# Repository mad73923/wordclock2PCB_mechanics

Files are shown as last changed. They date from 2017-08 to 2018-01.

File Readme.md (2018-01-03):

## Todos
- NRST C?
- ESP GPIO2 Pullup?
- SD CS
- Crystals C?
- SD Card shield
⁻ no THT components due to wall mount!?
- PCB boarder <-> Trace 0.25mm
- C instead of Bat?
- User Button debounce like F746 Discovery
- USB next to SD

### Copper: 2oz!

- Check USART Bootloader Pin capability!!! http://www.st.com/content/ccc/resource/technical/document/application_note/b9/9b/16/3a/12/1e/40/0c/CD00167594.pdf/files/CD00167594.pdf/jcr:content/translations/en.CD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

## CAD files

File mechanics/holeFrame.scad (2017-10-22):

// size - [x,y,z]
// radius - radius of corners
module roundedRect(size, radius)
{
	x = size[0];
	y = size[1];
	z = size[2];

	linear_extrude(height=z)
	hull()
	{
		// place 4 circles in the corners, with the given radius
		translate([(-x/2)+(radius/2), (-y/2)+(radius/2), 0])
		circle(r=radius);
	
		translate([(x/2)-(radius/2), (-y/2)+(radius/2), 0])
		circle(r=radius);
	
		translate([(-x/2)+(radius/2), (y/2)-(radius/2), 0])
		circle(r=radius);
	
		translate([(x/2)-(radius/2), (y/2)-(radius/2), 0])
		circle(r=radius);
	}
}

pcbMountR = 1;

module holeFrame(){
	difference(){
		cube([388,388,10]);
		translate([14+10+20/6,14+10+20/6,0]){
			for(i=[0:10]){
				for(j=[0:9]){
					translate([i*100/3,j*100/3,0])
						cylinder(30,14,14,true);
				}
			}
		}
        // minutes holes
        translate([388/2-(3*100/3)/2,11*100/3-15,0]){
            for(i=[0:3]){
                translate([i*100/3,0,0])
                cylinder(30,5,5,true);
            }
        }
        // ambient light sensor
        translate([388/2,11*100/3,0]){
            cylinder(30,5,5,true);
        }
        // PCB cutout
        translate([388/2-100/3,11*100/3+8.8,-1]){
            roundedRect([45,30,15],5);
        }
        translate([388/2+100/3,11*100/3+8.8,-1]){
            roundedRect([45,30,15],5);
        }
        //nose
        translate([388/2-10,11*100/3+8,-1]){
            cube([40,40,15]);
        }
        //cable input
        translate([388/2-55,11*100/3+6.5,-1])
            roundedRect([30,10,15],5);
        translate([388/2+55,11*100/3+6.5,-1])
            roundedRect([30,10,15],5);
        // PCB holes
        translate(pcbroot){
            translate([pcbHoleGap,pcbHoleGap,1])
            cylinder(30,pcbMountR,pcbMountR,true);
            translate([4,pcbsize[1]-pcbHoleGap,1])
            cylinder(30,pcbMountR,pcbMountR,true);
            translate([pcbsize[0],0,0]){
                translate([-pcbHoleGap,pcbHoleGap,1])
                cylinder(30,pcbMountR,pcbMountR,true);
                translate([-pcbHoleGap,pcbsize[1]-pcbHoleGap,1])
                cylinder(30,pcbMountR,pcbMountR,true);
            }
        }
	}
}

maskGerman = "ESXISTKFÜNFZEHNZWANZIGVIERTELGVORNACHBJSHALBEINSMJWZWEIDREIKFFVIERFÜNFJWSECHSSIEBENLACHTNEUNZEHNELFZWÖLFPCMUHR";
maskSwissGerman =  "ESKISCHAFÜFVIERTUBFZÄÄZWÄNZGSIVORABOHAUBIEPMEISZWÖISDRÜVIERIFÜFIQTSÄCHSISIBNIACHTINÜNIELZÄNIERBEUFIZWÖUFIAMUHR";

maskText = maskGerman;
maskFont = "Stencilia\\-A:style=Regular";
//maskFont = "Ruler Stencil Heavy:style=Standard";

module mask(){
	difference(){
		color("silver")
		cube([388,388,2]);
        translate([14+10+20/6,14+10+20/6,-1]){
			for(i=[0:9]){
				for(j=[0:10]){
					translate([j*100/3,i*100/3,0])
                    rotate([0,0,180])
						linear_extrude(height=5) text(maskText[i*11+10-j],  size=17.5, halign="center", valign="center", font=maskFont);
				}
			}
		}
        // minutes holes
        translate([388/2-(3*100/3)/2,11*100/3-15,0]){
            for(i=[0:3]){
                translate([i*100/3,0,0])
                cylinder(30,3,3,true);
            }
        }
        // ambient light sensor
        translate([388/2,11*100/3,0]){
            cylinder(30,3,3,true);
        }
	}
}

pcbroot = [388/2-65,11*100/3-9+1/3,-2];
pcbsize = [130,30,2];
pcbHoleR= 1.6;
pcbHoleGap = 4;

module pcb(){
    difference(){
        color("green")
        cube(pcbsize);
        translate([pcbHoleGap,pcbHoleGap,1])
        cylinder(5,pcbHoleR,pcbHoleR,true);
        translate([4,pcbsize[1]-pcbHoleGap,1])
        cylinder(5,pcbHoleR,pcbHoleR,true);
        translate([pcbsize[0],0,0]){
            translate([-pcbHoleGap,pcbHoleGap,1])
            cylinder(5,pcbHoleR,pcbHoleR,true);
            translate([-pcbHoleGap,pcbsize[1]-pcbHoleGap,1])
            cylinder(5,pcbHoleR,pcbHoleR,true);
        }
        translate([pcbsize[0]/2,8+2/3,0])
        cylinder(5,5,5,true);
    }
}

holeFrame();
translate([0,0,10]) mask();
translate(pcbroot) pcb();

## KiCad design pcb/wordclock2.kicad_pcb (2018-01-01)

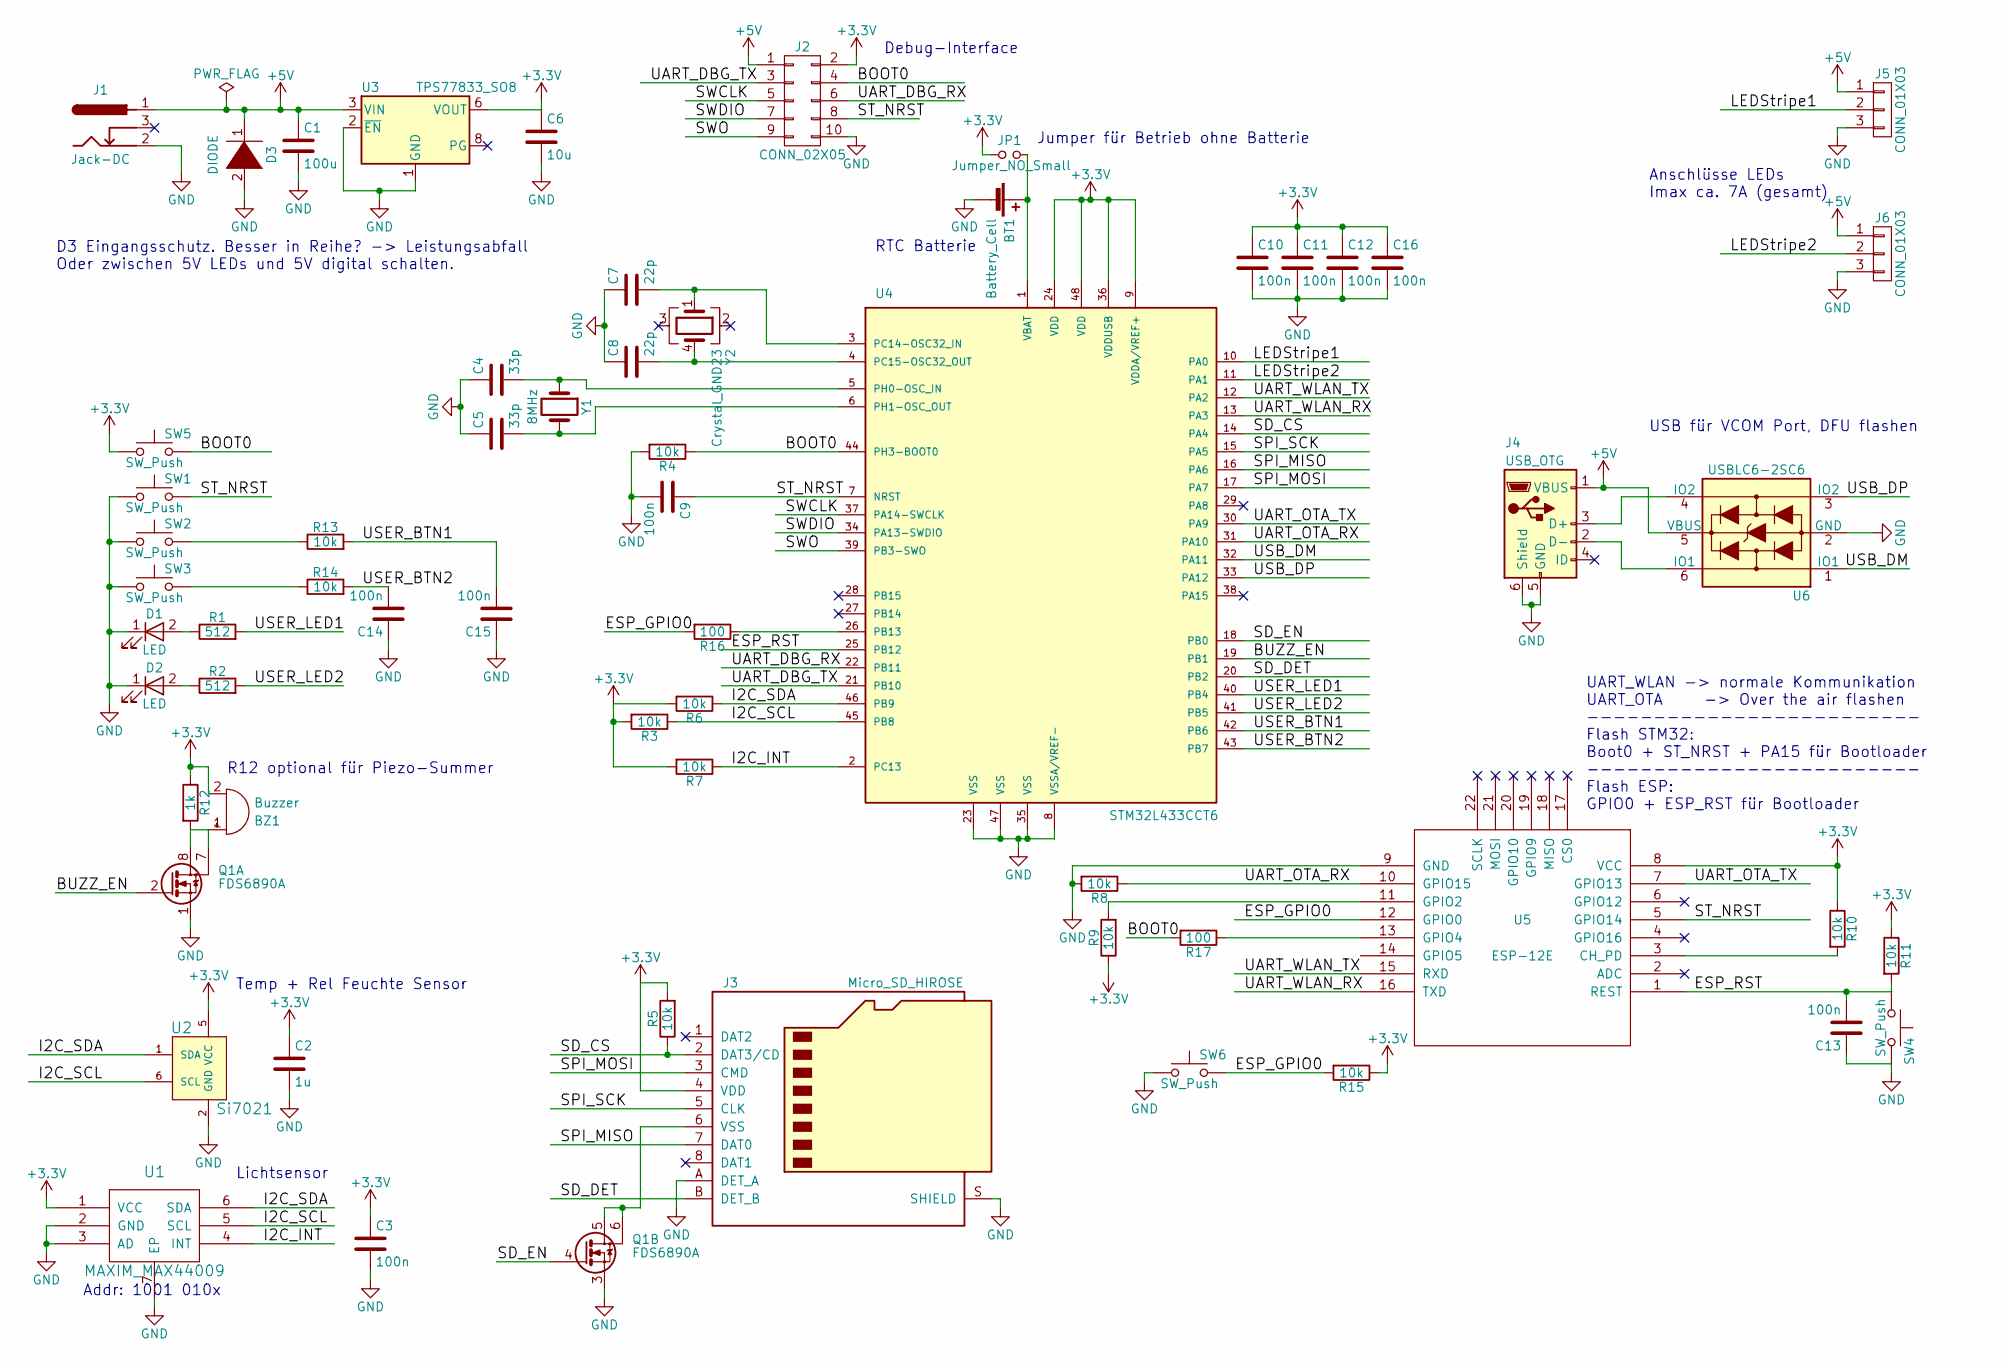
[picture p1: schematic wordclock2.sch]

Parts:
BT1: Battery_Cell; BK-890
BZ1: Buzzer; PKLCS1212E; Digi-Key 490-4683-1-ND
C1: 100u; CP_Tantalum_Case-D_EIA-7343-31_Hand
C2: 1u; C_0603_HandSoldering
C3, C9, C10, C11, C12, C13, C14, C15, C16: 100n; C_0603_HandSoldering
C4, C5: 33p; C_0603_HandSoldering
C6: 10u; C_0603_HandSoldering
C7, C8: 22p; C_0603_HandSoldering
D1, D2: LED; LED_0805_HandSoldering
D3: DIODE; D_PowerDI-123
J1: Jack-DC; BARREL_JACK
J2: CONN_02X05; SHF-105-01-L-D-RA
J3: Micro_SD_HIROSE; DM3D-SF
J4: USB_OTG; USB_Micro-B
J5, J6: CONN_01X03; CONN_HEADER_3POS
JP1: Jumper_NO_Small; SOLDER-JUMPER_1-WAY
Q1: FDS6890A; SOIC-8_3.9x4.9mm_Pitch1.27mm
R1, R2: 512; R_0603_HandSoldering
R3, R4, R5, R6, R7, R8, R9, R10, R11, R13, R14, R15: 10k; R_0603_HandSoldering
R12: 1k; R_0603_HandSoldering
R16, R17: 100; R_0603_HandSoldering
SW1, SW4, SW5, SW6: SW_Push; SW_SPST_KMR2
SW2, SW3: SW_Push; SW_Tactile_SPST_Angled_PTS645Vx39-2LFS
U1: MAXIM_MAX44009; MAX44009
U2: Si7021; Si7021-A20
U3: TPS77833_SO8; SOIC-8_3.9x4.9mm_Pitch1.27mm
U4: STM32L433CCT6; LQFP-48_7x7mm_Pitch0.5mm
U5: ESP-12E; ESP-12E_SMD
U6: USBLC6-2SC6; SOT-23-6
Y1: 8MHz; Crystal_SMD_HC49-SD_HandSoldering
Y2: Crystal_GND23; Crystal_SMD_SeikoEpson_MC306-4pin_8.0x3.2mm_HandSoldering

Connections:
+3V3: BZ1.2 (+), C2.1, C3.1, C6.1, C10.1, C11.1, C12.1, C16.1, J2.2, J3.4 (VDD), JP1.1, R3.2, R5.2, R6.2, R7.2, R9.1, R10.1, R11.1, R12.1, R15.1, SW5.1, U1.1 (VCC), U2.5 (VCC), U3.5 (VOUT), U3.6 (VOUT), U4.9 (VDDA/VREF+), U4.24 (VDD), U4.36 (VDDUSB), U4.48 (VDD), U5.8 (VCC)
+5V: C1.1, D3.1 (K), J1.1, J2.1, J4.1 (VBUS), J5.1, J6.1, U3.3 (VIN), U3.4 (VIN), U6.5 (VBUS)
/BOOT0: J2.4, R4.1, R17.2, SW5.2, U4.44 (PH3-BOOT0)
/BUZZ_EN: Q1.2 (G), U4.19 (PB1)
/ESP_GPIO0: R15.2, R16.2, SW6.2, U5.12 (GPIO0)
/ESP_RST: C13.2, R11.2, SW4.1, U4.25 (PB12), U5.1 (REST)
/I2C_INT: R7.1, U1.4 (INT), U4.2 (PC13)
/I2C_SCL: R3.1, U1.5 (SCL), U2.6 (SCL), U4.45 (PB8)
/I2C_SDA: R6.1, U1.6 (SDA), U2.1 (SDA), U4.46 (PB9)
/LEDStripe1: J5.2, U4.10 (PA0)
/LEDStripe2: J6.2, U4.11 (PA1)
/SD_CS: J3.2 (DAT3/CD), R5.1, U4.14 (PA4)
/SD_DET: J3.B (DET_B), U4.20 (PB2)
/SD_EN: Q1.4 (G), U4.18 (PB0)
/SPI_MISO: J3.7 (DAT0), U4.16 (PA6)
/SPI_MOSI: J3.3 (CMD), U4.17 (PA7)
/SPI_SCK: J3.5 (CLK), U4.15 (PA5)
/ST_NRST: C9.1, J2.8, SW1.2, U4.7 (NRST), U5.5 (GPIO14)
/SWCLK: J2.5, U4.37 (PA14-SWCLK)
/SWDIO: J2.7, U4.34 (PA13-SWDIO)
/SWO: J2.9, U4.39 (PB3-SWO)
/UART_DBG_RX: J2.6, U4.22 (PB11)
/UART_DBG_TX: J2.3, U4.21 (PB10)
/UART_OTA_RX: R8.1, U4.31 (PA10), U5.10 (GPIO15)
/UART_OTA_TX: U4.30 (PA9), U5.7 (GPIO13)
/UART_WLAN_RX: U4.13 (PA3), U5.16 (TXD)
/UART_WLAN_TX: U4.12 (PA2), U5.15 (RXD)
/USB_DM: U4.32 (PA11), U6.1 (IO1)
/USB_DP: U4.33 (PA12), U6.3 (IO2)
/USER_BTN1: C15.2, R13.2, U4.42 (PB6)
/USER_BTN2: C14.2, R14.2, U4.43 (PB7)
/USER_LED1: R1.2, U4.40 (PB4)
/USER_LED2: R2.2, U4.41 (PB5)
GND: BT1.2 (-), C1.2, C2.2, C3.2, C4.1, C5.1, C6.2, C7.1, C8.1, C9.2, C10.2, C11.2, C12.2, C13.1, C14.1, C15.1, C16.2, D1.1 (K), D2.1 (K), D3.2 (A), J1.2, J2.10, J3.A (DET_A), J3.S (SHIELD), J4.5 (GND), J4.6 (Shield), J5.3, J6.3, Q1.1 (S), Q1.3 (S), R4.2, R8.2, SW1.1, SW2.1, SW3.1, SW4.2, SW6.1, U1.2 (GND), U1.3 (AD), U1.7 (EP), U2.2 (GND), U3.1 (GND), U3.2 (~EN~), U4.8 (VSSA/VREF-), U4.23 (VSS), U4.35 (VSS), U4.47 (VSS), U5.9 (GND), U6.2 (GND)
unnamed: BT1.1 (+), JP1.2, U4.1 (VBAT)
unnamed: BZ1.1 (-), Q1.7, Q1.8 (D), R12.2
unnamed: C4.2, U4.5 (PH0-OSC_IN), Y1.1
unnamed: C5.2, U4.6 (PH1-OSC_OUT), Y1.2
unnamed: C7.2, U4.3 (PC14-OSC32_IN), Y2.1
unnamed: C8.2, U4.4 (PC15-OSC32_OUT), Y2.4
unnamed: D1.2 (A), R1.1
unnamed: D2.2 (A), R2.1
unnamed: J3.6 (VSS), Q1.5 (D), Q1.6
unnamed: J4.2 (D-), U6.6 (IO1)
unnamed: J4.3 (D+), U6.4 (IO2)
unnamed: R9.2, U5.11 (GPIO2)
unnamed: R10.2, U5.3 (CH_PD)
unnamed: R13.1, SW2.2
unnamed: R14.1, SW3.2
unnamed: R16.1, U4.26 (PB13)
unnamed: R17.1, U5.13 (GPIO4)

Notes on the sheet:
Addr: 1001 010x
D3 Eingangsschutz. Besser in Reihe? -> Leistungsabfall Oder zwischen 5V LEDs und 5V digital schalten.
Jumper für Betrieb ohne Batterie
Anschlüsse LEDs Imax ca. 7A (gesamt)
Debug-Interface
R12 optional für Piezo-Summer
Temp + Rel Feuchte Sensor
Lichtsensor
UART_WLAN -> normale Kommunikation UART_OTA -> Over the air flashen ------------------------- Flash STM32: Boot0 + ST_NRST + PA15 für Bootloader ------------------------- Flash ESP: GPIO0 + ESP_RST für Bootloader
USB für VCOM Port, DFU flashen
RTC Batterie

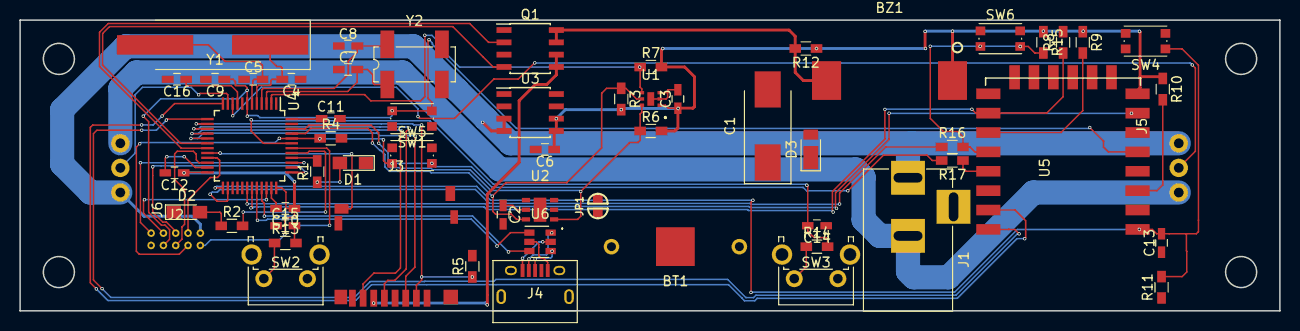
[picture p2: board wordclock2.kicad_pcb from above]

Board: 2 copper layers, 130.0 x 30.0 mm, 60 parts (0 on the bottom side), 51 nets.

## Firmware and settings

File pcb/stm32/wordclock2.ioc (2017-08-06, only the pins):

Mcu.UserName=STM32L433CCTx
PA0.GPIO_Label=LEDStripe1
PA0.Signal=S_TIM2_CH1
PA1.GPIO_Label=LEDStripe2
PA1.Signal=S_TIM2_CH2
PA10.GPIO_Label=UART_OTA_RX
PA10.Signal=USART1_RX
PA11.Signal=USB_DM
PA12.Signal=USB_DP
PA2.GPIO_Label=UART_WLAN_TX
PA2.Signal=USART2_TX
PA3.GPIO_Label=UART_WLAN_RX
PA3.Signal=USART2_RX
PA4.GPIO_Label=SD_CS
PA4.Signal=GPIO_Output
PA5.Signal=SPI1_SCK
PA6.Signal=SPI1_MISO
PA7.Signal=SPI1_MOSI
PA9.GPIO_Label=UART_OTA_TX
PA9.Signal=USART1_TX
PB0.GPIO_Label=SD_EN
PB0.Signal=GPIO_Output
PB1.GPIO_Label=BUZZ_EN
PB1.Signal=GPIO_Output
PB10.GPIO_Label=UART_DBG_TX
PB10.Signal=USART3_TX
PB11.GPIO_Label=UART_DBG_RX
PB11.Signal=USART3_RX
PB12.GPIO_Label=ESP_RST
PB12.Signal=GPIO_Output
PB13.GPIO_Label=ESP_GPIO0
PB13.Signal=GPIO_Output
PB2.GPIO_Label=SD_DET
PB2.Signal=GPXTI2
PB5.GPIO_Label=USER_LED2
PB5.Signal=GPIO_Output
PB6.GPIO_Label=USER_BTN1
PB6.Signal=GPXTI6
PB7.GPIO_Label=USER_BTN2
PB7.Signal=GPXTI7
PB8.Signal=I2C1_SCL
PB9.Signal=I2C1_SDA
PC13.GPIO_Label=I2C_INT
PC13.Signal=GPXTI13

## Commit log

2017-06-17 Initialer Commit
    [holeFrame.scad]
2017-08-05 added datasheets
    [wordclock2.sch]
2017-08-06 rescued scad file
    [holeFrame.scad]
2017-08-06 annotated schematic
    [wordclock2.sch]
2017-09-02 progres, new footprint, datasheet
    [wordclock2.sch]
2017-10-28 progress, added 32kHz Crystal datasheet
    [wordclock2.kicad_pcb, wordclock2.sch]
2017-10-28 smaller battery mount
    [wordclock2.kicad_pcb, wordclock2.sch]
2017-12-18 deleted submodul, added resistor on GPIO line
    [wordclock2.sch]
2017-12-18 changed to 0603 components, added schematic notes
    [wordclock2.kicad_pcb, wordclock2.sch]
2017-12-18 drawing notes, moved hole lines to fab layer
    [wordclock2.kicad_pcb]
2017-12-21 added resistor in series BOOT0, button protection
    [wordclock2.sch]
2017-12-21 updated sd-card detection pad
    [wordclock2.kicad_pcb, wordclock2.sch]
2017-12-21 added supercap to BOM, user button datasheet
2017-12-25 first tracks
    [wordclock2.kicad_pcb, wordclock2.sch]
2018-01-01 ESD Diodes USB, many tracks, huge progress
    [wordclock2.kicad_pcb, wordclock2.sch]
